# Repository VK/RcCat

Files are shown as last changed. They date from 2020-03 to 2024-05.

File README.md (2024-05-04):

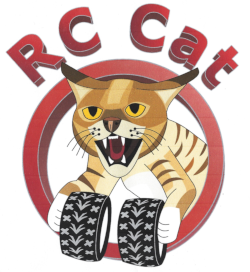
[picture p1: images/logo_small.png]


# VK RcCat :cat:

  


**RcCat provides next generation driving aids for Rc Cars.**

Ramp Jumps                     |  Garden Jumps                      |
:-----------------------------:|:----------------------------------:
RcCat Ramp Jumps (https://www.youtube.com/watch?v=5Ehqny6YLAg "RcCat Ramp Jumps")   |  RcCat Garden Jumps (https://www.youtube.com/watch?v=Mkig3it6fFk "RcCat Garden Jumps")   |

A microcontroller with several sensors intercepts the drive commands of the receiver
to send optimized signals to the steering servo and the speed controller.
During the flights, a minimalistic neural network is used to determine the next action.
As a result, my RcCat can land on all fours if it falls to the ground from a distance of about one meter.

My prototype is based on 1:16 **Traxxas Mini E-Revo**:

Car top view                   |  Car bottom view                   | Monitor App
:-----------------------------:|:----------------------------------:|:----------------------:
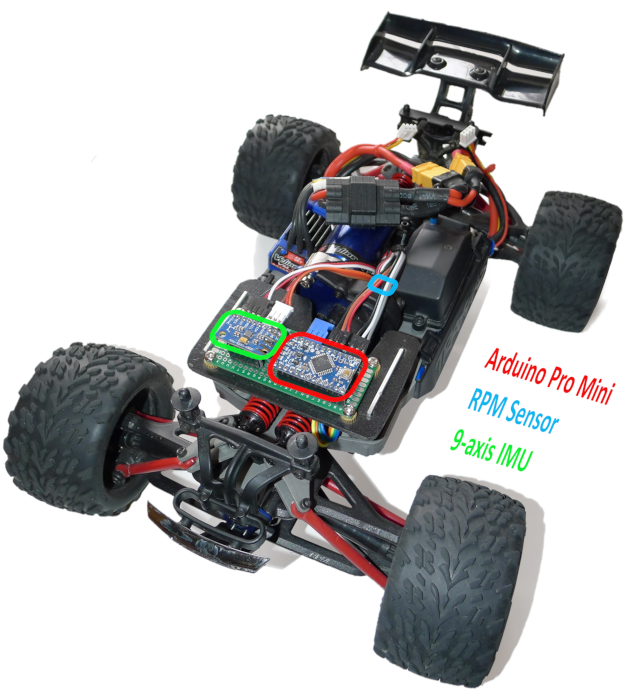
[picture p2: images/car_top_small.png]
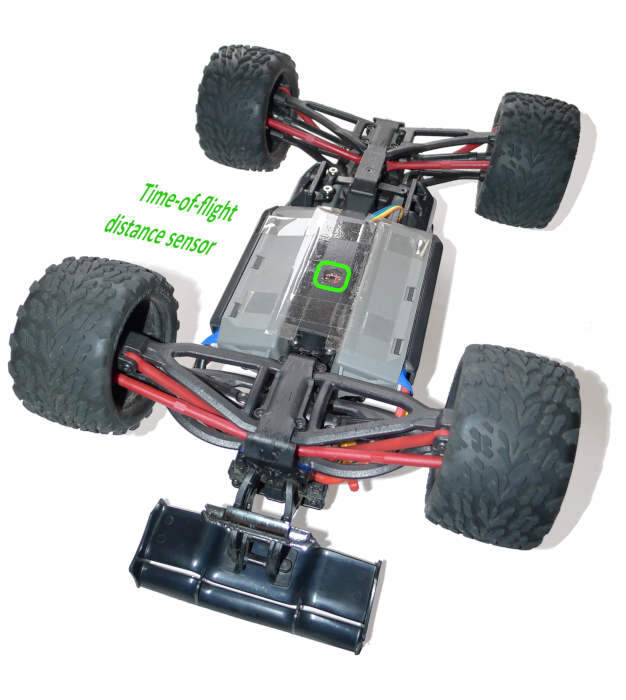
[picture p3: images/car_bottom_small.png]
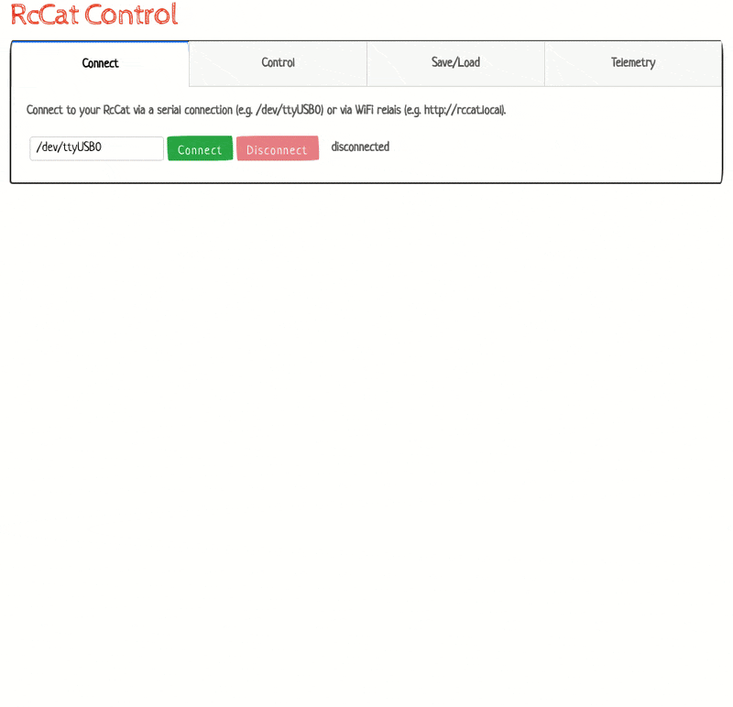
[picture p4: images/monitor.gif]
  |    | 

## Repo parts
* **[car_firmware](/car_firmware):** The core firmware of RcCat

* **[wlan_repeater](/wlan_repeater):** Serial to Wlan bridge to send telemetry data via wlan during driving and update drive parameters.

* **[pyapps](/pyapps):** Additional python tools to analyze RcCat telemetry data and adjust drive characteristics

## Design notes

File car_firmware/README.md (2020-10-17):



# VK RcCat Firmware



The main control of RcCat runs on a 5V Arduino Mini Pro. Feel free to use this repo and build your own RcCat firmware optimized for your RC model.

The firmware can be built form this PlatformIO project and consists of a few [classes](/car_firmware/src).

## Schematic breadboard setup
The components are connected as follows and communicate either via **I2C** (IMU and range sensor) bus or **PWM** (receiver, servo, RPM sensor and speed controller)
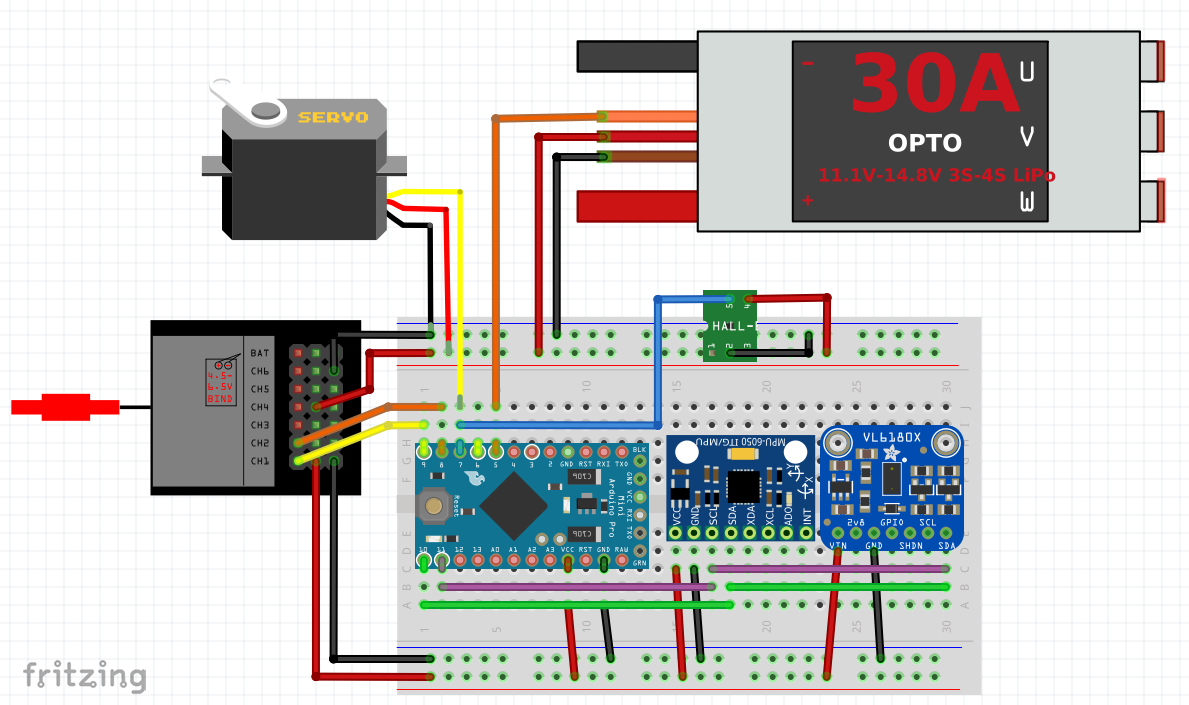
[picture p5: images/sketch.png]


## Bill of materials
* Arduino Pro Mini 5V
  https://store.arduino.cc/arduino-pro-mini
* 9 axis IMU MPU9250 @ 5Volt
  (many different possible)
* ToF range sensors VL6180
  https://www.sparkfun.com/products/12785
* Traxxas 6520 RPM Sensor

##  Build
Install [PlatformIO](https://platformio.org/) for VsCode or your favorite IDE.
```
platformio run --target upload --target monitor
```

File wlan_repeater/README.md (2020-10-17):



# VK RcCat WLAN repeater



In order to have the car telemetry data during test drives, I use a WLAN relay connected to the serial interface of the Arduino Mini Pro. The relais buffers up to 32kB of the sensor output in a circular buffer (a few seconds), which can be collected via WiFi.

Several WiFi enabled microcontrollers are possible, but I use a spare ESP8266 development board and directly wire it like:
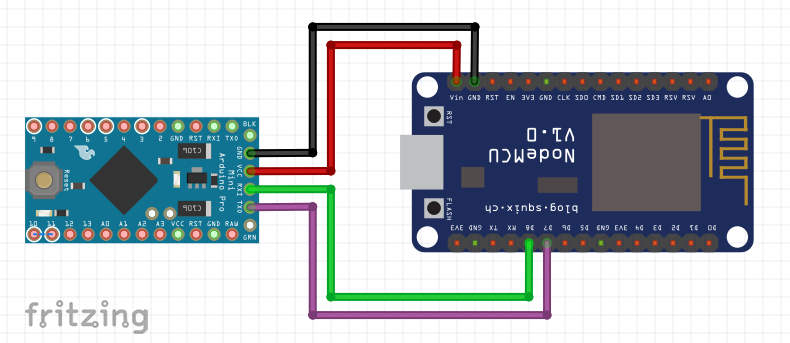
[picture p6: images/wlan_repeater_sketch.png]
 

 The ESP8266 creates a open WiFi with ssid `"RcCat-Wifi"` and publishes a web interface at [http://rccat.local/](http://rccat.local/).

 ### WiFi Endpoints
 * http://rccat.local/get serves a binary dump of the internal telemetry buffer.
 * http://rccat.local/write sends the body of the request via serial connection to the Mini Pro. This can be used to send controll commands or update drive parameters.
 * http://rccat.local/clear clears the recored telemetry buffer.

### Example


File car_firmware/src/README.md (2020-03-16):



# VK RcCat Firmware

The firmware from RcCat consists of a few classes.

The main logic is handeled by the `Controller` class. For more information about the different `DriveStates` see the [ControllerStates subfolder](./ControllerStates).

To do this, the `Controller` collects information from the
* `IMU` class about rool and pitch 
* `RangeFinder`class about the ground distance
* `Receiver` class about the steering and acceleration input of the driver, as well as the current speed.

## Class overview
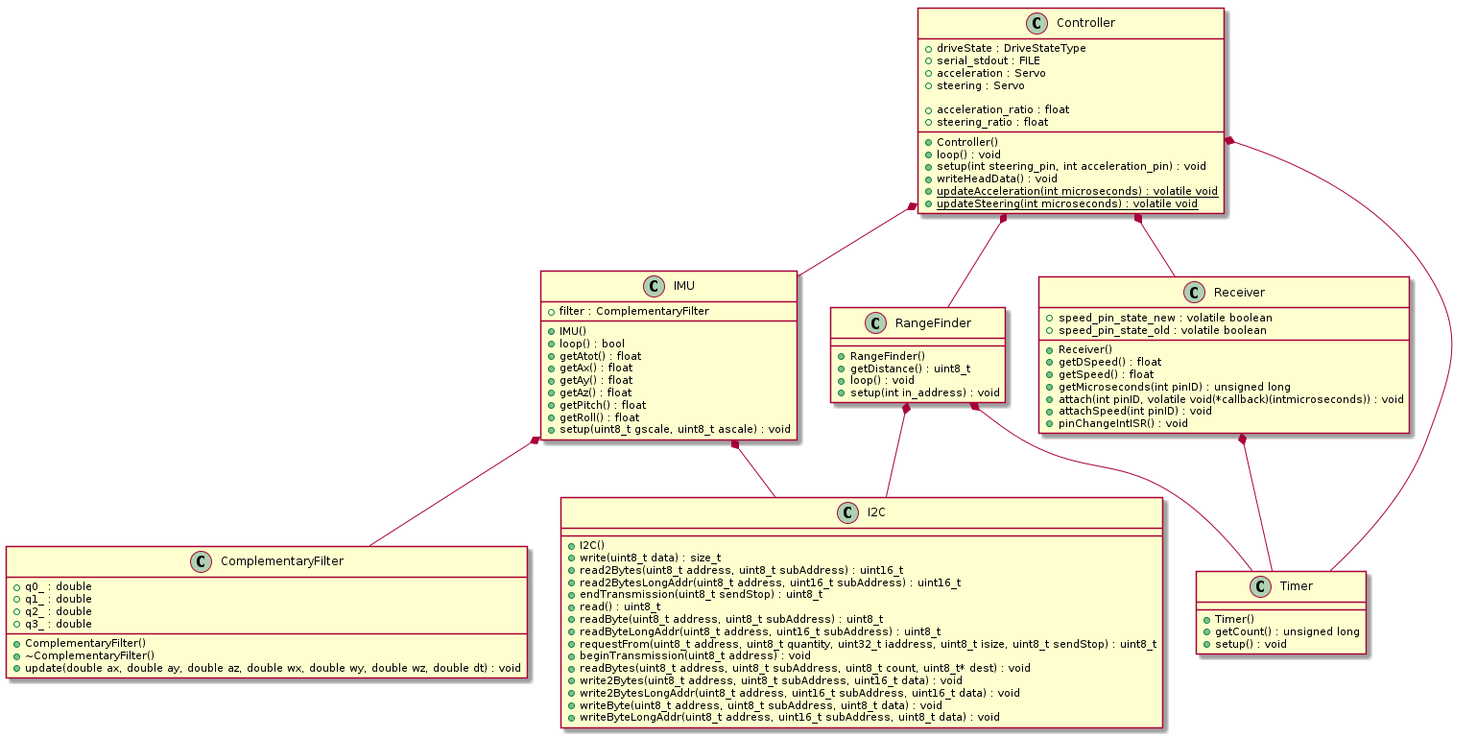
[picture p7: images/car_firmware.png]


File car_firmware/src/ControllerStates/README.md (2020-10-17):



# RcCat Controller States

The `RcCat::Controller` knows 5 different state types, which are automatically chosen depending on sensor data. 

```cpp
enum DriveStateType {
     normal   = 1,
     falling  = 2,
     elevated = 3,
     jumping  = 4,
     external = 5
     };
```
Depending on the status of the `RcCat::Controller`, either the commands from the remote control are passed (directly or modified) to the steering servo or the speed controller, or the control of the car is completely taken over by the `RcCat::Controller`. 
Below is a minimalistic overview of the different drive states.

## Normal
The `DriveStateType::normal` is always active when the car is sufficiently close to the ground and no external commands are triggered.
There is a so-called `saveMode` which capps the the maximum speed with the data of the rpm sensor.
This `saveMode` can be enabled/dissabled by giving full trottle/break once the  car is elevated. This helps to easily pass the car to curious kids.
Outside of the `saveMode` the pitch data of the gyro is used to reduce the throttle to give maximal acceleration without wheelies or rollovers.

## Elevated
The `DriveStateType::elevated` is entered when the ground distance is high and the speed of the car almost  zero. In this state the car steers straight ahead and stops the main motor to prepare for the possible upcoming `DriveStateType::falling`.

## Falling
Once the car is in the `DriveStateType::falling` the main is used to bring the car the level befor reaching the ground. This is done via a small neural network. The next state is `DriveStateType::normal` once the car reaches the ground.

## Jumping
The `DriveStateType::jumping` is entered when the ground distance is higher than a few centimeters and the speed of the car is sufficiently high. This is done by the same neural network. In the past, two different PID controllers were used for this.
The controler goes back to `DriveStateType::normal` once the groud distance is small again. 

## External
The `DriveStateType::external` can be entered by sending a command to the microcontroller over the serial bus. The state is only enterd if the radio input was close to zero for the last 5 seconds, and goes back to `DriveStateType::normal` if a radio signal with different drive commands are received.

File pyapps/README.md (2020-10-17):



# VK RcCat Python Apps

This section contains a basic `monitor.py` Python app and an interface library for recording and monitoring telemetry data of RcCat and remote control steering, acceleration and internal parameters.

## The App in action


## Setup & Run
```javascript
//create and enter environment
pipenv install
pipenv shell

//start app
python monitor.py
```

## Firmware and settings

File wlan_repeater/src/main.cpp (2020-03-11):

/* This file is part of VK RcCat.
 *
 * Copyright 2020 Viktor Krueckl (viktor@krueckl.de). All Rights Reserved.
 *
 * Licensed under the Apache License, Version 2.0 (the "License");
 * you may not use this file except in compliance with the License.
 * You may obtain a copy of the License at
 *
 *     http://www.apache.org/licenses/LICENSE-2.0
 *
 * Unless required by applicable law or agreed to in writing, software
 * distributed under the License is distributed on an "AS IS" BASIS,
 * WITHOUT WARRANTIES OR CONDITIONS OF ANY KIND, either express or implied.
 * See the License for the specific language governing permissions and
 * limitations under the License.
 * ==============================================================================
 */

#include <DNSServer.h>
#include <ESP8266WebServer.h>
#include <ESP8266WiFi.h>
#include <ESP8266mDNS.h>

const byte DNS_PORT = 53;       // Capture DNS requests on port 53
IPAddress apIP(10, 10, 10, 1);  // Private network for server
DNSServer dnsServer;            // Create the DNS object
ESP8266WebServer webServer(80); // HTTP server

String dummyResponseHTML =
    ""
    "<!DOCTYPE html><html><head><title>RcCat</title></head><body>"
    "<h1>Hello RcCat User</h1><p>This is a captive portal for the"
    "RcCat serial relais. The monitor web app can use this"
    "interface to record car data on the fly."
    "</p></body></html>";

String emptyResponseJSON = "{}";

#define BUFFER_SIZE 32768
char binaryBuffer[BUFFER_SIZE];
unsigned int bufferStart = 0;
unsigned int bufferEnd = 0;

void clear_buffer() {
  bufferStart = 0;
  bufferEnd = 0;
  for (int i = 1; i < BUFFER_SIZE; i++)
    binaryBuffer[i] = 0;
}

void setup() {

  // initialize drive data buffer
  clear_buffer();

  // initialize wifi
  WiFi.mode(WIFI_AP);
  WiFi.softAPConfig(apIP, apIP, IPAddress(255, 255, 255, 0));
  WiFi.softAP("RcCat-Wifi");

  // start dns server for captive portal
  dnsServer.start(DNS_PORT, "*", apIP);

  // register rccat.local dns entry
  if (!MDNS.begin("rccat")) {
    Serial.println("Error setting up MDNS responder!");
  }
  MDNS.addService("http", "tcp", 80);

  // replay to all unknown requests with same HTML
  webServer.onNotFound(
      []() { webServer.send(200, "text/html", dummyResponseHTML); });

  // clear the drive data buffer
  webServer.on("/clear", [] {
    webServer.send(200, "application/json", emptyResponseJSON);
    clear_buffer();
  });

  // send the request data directly over serial to the RcCat
  webServer.on("/write", [] {
    Serial.print(webServer.arg("plain"));
    webServer.send(200, "application/json", emptyResponseJSON);
  });

  // send the buffered drive data as binary file
  webServer.on("/get", [] {
    WiFiClient client = webServer.client();

    client.print("HTTP/1.1 200 OK\r\n");
    client.print("Content-Disposition: attachment; filename=rccat.bin\r\n");
    client.print("Content-Type: application/octet-stream\r\n");

    // if there was no buffer overflow, we send back the size
    if (bufferStart == 0) {
      client.print("Content-Length: " + String(bufferEnd) + "\r\n");
    } else {
      // with an overflow we will dump the full buffer
      client.print("Content-Length: " + String(BUFFER_SIZE) + "\r\n");
    }
    client.print("Connection: close\r\n");
    client.print("Access-Control-Allow-Origin: *\r\n");
    client.print("\r\n");

    if (bufferStart == 0) {
      // append the buffer, to the end
      client.write((const char *)(binaryBuffer), bufferEnd);
    } else {

      // first append the buffer from the start to the buffer end
      client.write((const char *)(&(binaryBuffer[bufferStart - 1])),
                   BUFFER_SIZE - bufferStart + 1);
      // then the buffer start to the end
      if (bufferEnd > 0)
        client.write((const char *)(binaryBuffer), bufferEnd);
    }

    clear_buffer();
  });

  // start the webserver
  webServer.begin();

  // set baud rate and switch to RX TX pins
  Serial.begin(115200);
  Serial.swap();
}

void loop() {
  // loop functions for DNS, WebServer and local DNS
  dnsServer.processNextRequest();
  webServer.handleClient();
  MDNS.update();

  // handle serial input
  if (Serial.available() > 0) // Checks is there any data in buffer
  {
    // put it into the internal running buffer array
    binaryBuffer[bufferEnd] = char(Serial.read());

    // go to the next buffer Position
    bufferEnd++;
    // check the buffer end overflow
    if (bufferEnd == BUFFER_SIZE) {
      bufferEnd = 0;
    }
    // once we have a buffer overflow, the buffer start moves too
    if (bufferStart == bufferEnd) {
      bufferStart = bufferEnd + 1;
    }
    // and we can also get a buffer start overflow
    if (bufferStart == BUFFER_SIZE) {
      bufferStart = 0;
    }
  }
}

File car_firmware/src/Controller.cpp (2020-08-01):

/* This file is part of VK RcCat.
 *
 * Copyright 2020 Viktor Krueckl (viktor@krueckl.de). All Rights Reserved.
 *
 * Licensed under the Apache License, Version 2.0 (the "License");
 * you may not use this file except in compliance with the License.
 * You may obtain a copy of the License at
 *
 *     http://www.apache.org/licenses/LICENSE-2.0
 *
 * Unless required by applicable law or agreed to in writing, software
 * distributed under the License is distributed on an "AS IS" BASIS,
 * WITHOUT WARRANTIES OR CONDITIONS OF ANY KIND, either express or implied.
 * See the License for the specific language governing permissions and
 * limitations under the License.
 * ==============================================================================
 */

#include "Controller.h"

#include "IMU.h"
#include "RangeFinder.h"
#include "Receiver.h"
#include "Timer.h"

int serial_putchar(char c, FILE *f)
{
  if (c == '\n')
    serial_putchar('\r', f);
  return Serial.write(c) == 1 ? 0 : 1;
}

namespace RcCat
{

  Controller controller;

  Controller::Controller()
  {
    driveState = normal;

    speed = 0.0;
    dspeed = 0.0;

    for (int i = 0; i < MEMORY_LENGTH; i++)
    {
      a_tot_mem[i] = 100.0;
      groundDist_mem[i] = 0;
      timer_mem[i] = 0;
    }

    // setup output
    // Set up stdout
    fdev_setup_stream(&serial_stdout, serial_putchar, NULL, _FDEV_SETUP_WRITE);
    stdout = &serial_stdout;
  }

  void Controller::setup(int steering_pin, int acceleration_pin)
  {
    steering_ratio = 1.0;
    acceleration_ratio = 1.0;
    pinMode(13, OUTPUT);
    steering.attach(steering_pin);
    acceleration.attach(acceleration_pin);
    saveMode = false;
  }

  void Controller::updateDriveState()
  {

    if (driveState == external)
      return;

    // decide driveState
    bool groundDist_smaller_threshold = false;

    for (int i = 0; i < MEMORY_LENGTH; i++)
    {
      if (groundDist_mem[i] < MINIMAL_GROUND_DISTANCE)
      {
        groundDist_smaller_threshold = true;
      }
    }

    if (driveState == falling || driveState == jumping)
    {
      if (groundDist_smaller_threshold)
      {
        startNormal();
        driveState = normal;
      }
    }
    else
    {

      if (driveState == elevated &&
          a_tot_mem[MEMORY_LENGTH - 1] < MINIMAL_ABSOLUTE_GRAVITY)
      {
        driveState = falling;
        //startFalling();
      }
      else if (groundDist_smaller_threshold)
      {
        startNormal();
        driveState = normal;
      }
      else
      {

        if (speed > .5)
        {
          driveState = jumping;
          //startJumping();
        }
        else
        {
          driveState = elevated;
        }
      }

    } // if flying
  }

  volatile void Controller::updateSteering(int microseconds)
  {
    // initial bridge input
    // controller.steering.writeMicroseconds(1400 - (microseconds - 1500));
    if (controller.driveState == DriveStateType::normal)
    {
      controller.steering.writeMicroseconds(1400 - controller.steering_ratio *
                                                       (microseconds - 1500));
    }
  }

  volatile void Controller::updateAcceleration(int microseconds)
  {
    // initial bridge input
    // controller.acceleration.writeMicroseconds(microseconds);
    if (controller.driveState == DriveStateType::normal)
    {
      if (controller.acceleration_ratio == 1.0f)
      {
        controller.acceleration.writeMicroseconds(microseconds);
      }
      else
      {
        controller.acceleration.writeMicroseconds(
            1500 + controller.acceleration_ratio * (microseconds - 1500));
      }
    }
  }

  void Controller::collectData()
  {
    // update floating memory
    for (int i = 0; i < MEMORY_LENGTH - 1; i++)
    {
      a_tot_mem[i] = a_tot_mem[i + 1];
      ax_mem[i] = ax_mem[i + 1];
      ay_mem[i] = ay_mem[i + 1];
      az_mem[i] = az_mem[i + 1];
      groundDist_mem[i] = groundDist_mem[i + 1];
      roll_mem[i] = roll_mem[i + 1];
      pitch_mem[i] = pitch_mem[i + 1];
      timer_mem[i] = timer_mem[i + 1];
    }

    // save new values
    a_tot_mem[MEMORY_LENGTH - 1] = imu.getAtot() * 100;
    ax_mem[MEMORY_LENGTH - 1] = imu.getAx() * 100;
    ay_mem[MEMORY_LENGTH - 1] = imu.getAy() * 100;
    az_mem[MEMORY_LENGTH - 1] = imu.getAz() * 100;
    groundDist_mem[MEMORY_LENGTH - 1] = rangeFinder.getDistance();
    timer_mem[MEMORY_LENGTH - 1] = timer.getCount();
    pitch_mem[MEMORY_LENGTH - 1] = 10000 * imu.getPitch();
    roll_mem[MEMORY_LENGTH - 1] = 10000 * imu.getRoll();

    int helper;
    roll_av = 0.5 * roll_mem[MEMORY_LENGTH - 1];
    roll_ch = roll_av;
    helper = 0.5 * roll_mem[MEMORY_LENGTH - 2];
    roll_av += helper;
    roll_ch -= helper;

    pitch_av = 0.5 * pitch_mem[MEMORY_LENGTH - 1];
    pitch_ch = pitch_av;
    helper = 0.5 * pitch_mem[MEMORY_LENGTH - 2];
    pitch_av += helper;
    pitch_ch -= helper;

    speed = receiver.getSpeed();
    dspeed = receiver.getDSpeed();

    steering_receiver = receiver.getMicroseconds(0) - 1500;
    acceleration_receiver = receiver.getMicroseconds(1) - 1500;
  }

  void Controller::writeHeadData()
  {

    Serial.println("#Output meas data");
    Serial.print("#t");
    Serial.print("\t");
    // receiver_input
    Serial.print("#steering_receiver");
    Serial.print("\t");
    Serial.print("acceleration_receiver");
    Serial.print("\t");

    /// last values
    ///=================
    // acceleration_directed
    Serial.print("ax_0");
    Serial.print("\t");
    Serial.print("ay_0");
    Serial.print("\t");
    Serial.print("az_0");
    Serial.print("\t");
    // gyro_input
    Serial.print("a_tot_0");
    Serial.print("\t");
    Serial.print("pitch_0");
    Serial.print("\t");
    Serial.print("roll_0");
    Serial.print("\t");

    // ground distance is very slow, so we only use the last value
    Serial.print("groundDist");
    Serial.print("\t");

    // motor_speed
    Serial.print("speed");
    Serial.print("\t");

    // servo_last_values
    Serial.print("steering_out");
    Serial.print("\t");
    Serial.print("acceleration_out");
    Serial.print("\t");

    // drive_state
    Serial.println("driveState");
  }

  void Controller::writeData()
  {
    printf("%lu\t%i\t%i\t%i\t%i\t%i\t%i\t%i\t%i\t%i\t%i\t%i\t%i\t%i\n",
           timer_mem[MEMORY_LENGTH - 1],
           steering_receiver, acceleration_receiver, ax_mem[MEMORY_LENGTH - 1],
           ay_mem[MEMORY_LENGTH - 1], az_mem[MEMORY_LENGTH - 1],
           a_tot_mem[MEMORY_LENGTH - 1], pitch_mem[MEMORY_LENGTH - 1],
           roll_mem[MEMORY_LENGTH - 1], groundDist_mem[MEMORY_LENGTH - 1],
           int(speed * 10), 1400 - steering.readMicroseconds(),
           acceleration.readMicroseconds() - 1500, driveState);
  }

  void Controller::readData()
  {
    int value = Serial.read();

    if (value != -1)
    {

      if (value == 120)
      {
        driveState = normal;
      }
      else
      {
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

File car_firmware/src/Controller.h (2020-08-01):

/* This file is part of VK RcCat.
 *
 * Copyright 2020 Viktor Krueckl (viktor@krueckl.de). All Rights Reserved.
 *
 * Licensed under the Apache License, Version 2.0 (the "License");
 * you may not use this file except in compliance with the License.
 * You may obtain a copy of the License at
 *
 *     http://www.apache.org/licenses/LICENSE-2.0
 *
 * Unless required by applicable law or agreed to in writing, software
 * distributed under the License is distributed on an "AS IS" BASIS,
 * WITHOUT WARRANTIES OR CONDITIONS OF ANY KIND, either express or implied.
 * See the License for the specific language governing permissions and
 * limitations under the License.
 * ==============================================================================
 */

#ifndef RCAT_CONTROLLER_H
#define RCAT_CONTROLLER_H

#include <Arduino.h>
#include <Servo.h>

namespace RcCat
{


//configuration for running averages
#define MEMORY_LENGTH 3
#define MINIMAL_ABSOLUTE_GRAVITY 20
#define MINIMAL_GROUND_DISTANCE 65

  class Controller
  {
  public:
    Controller();

  public:
    void setup(int steering_pin, int acceleration_pin);
    void loop();

    void writeHeadData();

  public:
    enum DriveStateType
    {
      normal = 1,
      falling = 2,
      elevated = 3,
      jumping = 4,
      external = 5
    };
    DriveStateType driveState;
    Servo steering;
    Servo acceleration;
    float steering_ratio;
    float acceleration_ratio;
    FILE serial_stdout;

  public:
    static volatile void updateSteering(int microseconds);
    static volatile void updateAcceleration(int microseconds);

  private:
    int a_tot_mem[MEMORY_LENGTH];
    int ax_mem[MEMORY_LENGTH];
    int ay_mem[MEMORY_LENGTH];
    int az_mem[MEMORY_LENGTH];

    int pitch_mem[MEMORY_LENGTH];
    int roll_mem[MEMORY_LENGTH];
    int groundDist_mem[MEMORY_LENGTH];
    unsigned long timer_mem[MEMORY_LENGTH];


  private:
    bool blinkState;
    int blinkCounter;
    bool saveMode;

  private:
    int roll_ch;
    int roll_av;
    int pitch_ch;
    int pitch_av;
    int a_tot;
    float speed;
    float dspeed;

  private:
    int steering_receiver;
    int acceleration_receiver;

  private:
    float p_001_normal_pitch_min = 1000.0f;
    float p_002_normal_pitch_ratio = 30.0f;
    float p_003_normal_acc_offset = 1.2f;
    float p_004_normal_acc_min = 0.2f;

  private:
    void collectData();

    void updateDriveState();

    //the following functions are moved to extra files in the ControllerStates folder!
    void updateNormal();
    void updateElevated();
    void updateCatBrain();

    void startNormal();


    void setParameter(int id, int value);
    void commandExternal(int steer, int accel);
    void updateExternal();


    void writeData();
    void readData();
    
  };

  extern Controller controller;

} // namespace RcCat
#endif

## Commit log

2020-03-03 add servo to platform io
2020-03-08 update imu
2020-03-11 readme for wlan repeater
    [wlan_repeater_sketch.fzz]
